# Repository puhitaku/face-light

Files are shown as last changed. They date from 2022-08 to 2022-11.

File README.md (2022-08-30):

# Face Light

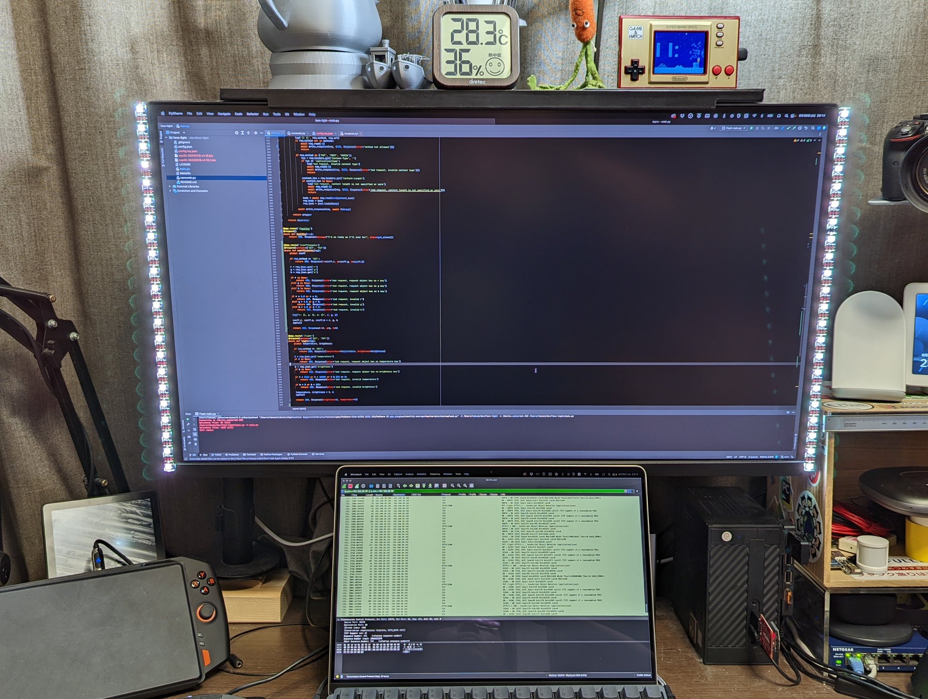
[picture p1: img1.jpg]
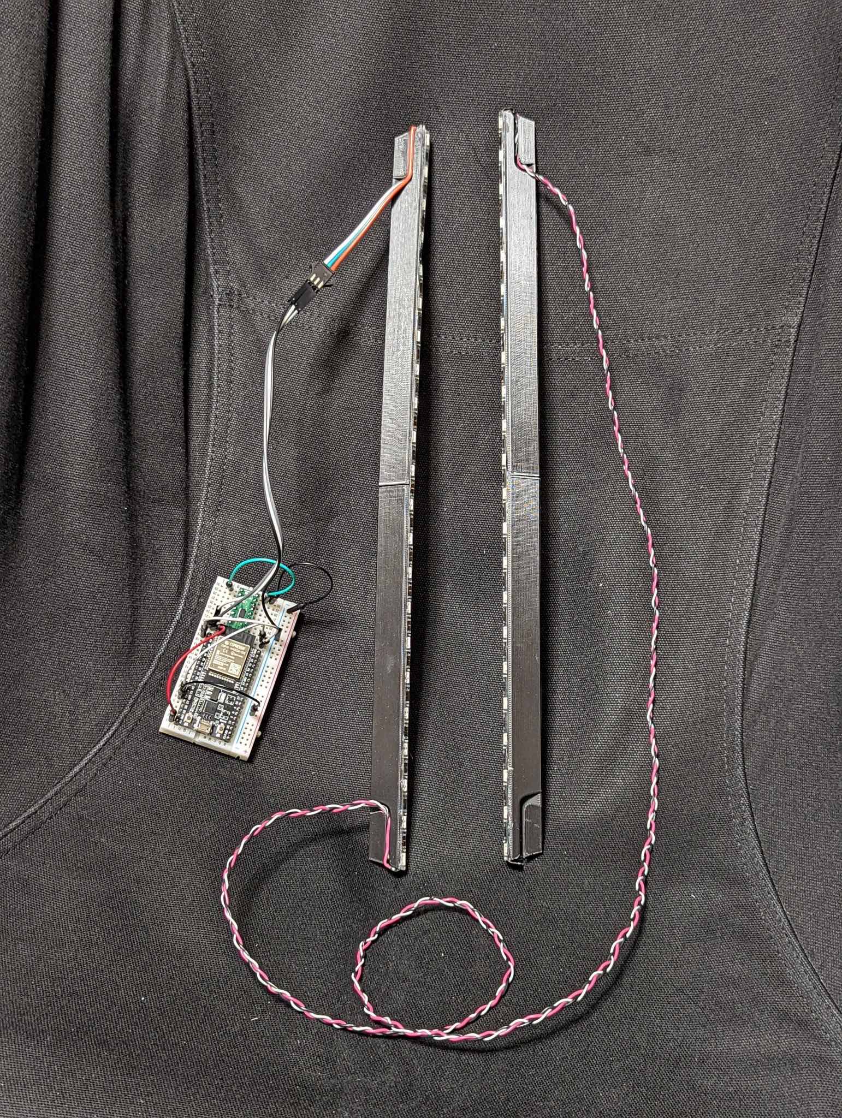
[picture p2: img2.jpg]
&nbsp;&nbsp;

3D-printed bars + NeoPixel LED strip + ESP32 + MicroPython = Face Light

### How to make yours

Prepare parts:

 - Open `face_light_bar.f3d`, adjust the length, and print it
   (A thin wooden bar basically does the same thing so you actually don't have to print it)
 - Any ESP32 module w/ USB-UART converter
 - Any NeoPixel(-compatible) LED strip
 - Level shifter between 3.3V -> 5V (for example: Fairchild Semiconductor FXMA108)

First, [install MicroPython on the ESP32 module](https://micropython.org/download/?port=esp32) (I tested it on MicroPython 1.15).

Fill the configuration file `config.json`.

 - `ssid`: your Wi-Fi AP's ESSID
 - `psk`: the pre-shared key (password)
 - `hostname`: ESP32's host name (advertised by mDNS)
 - `n_leds`: number of LEDs the strip has
 - `pin`: the pin number that the LED strip's DIN is connected to
 - `brightness`: default brightness on boot
 - `temperature`: default color temperature on boot
 - `coeff_r`: default coefficient of R channel on boot
 - `coeff_g`: default coefficient of G channel on boot
 - `coeff_b`: default coefficient of B channel on boot

After installing [ampy](https://github.com/scientifichackers/ampy), deploy the code and configuration.

```shell
ampy -p {serial_device} put main.py
ampy -p {serial_device} put nanoweb.py
ampy -p {serial_device} put config.json
```

Connect parts like:

 - ESP32 Vcc 3.3V -> Level shifter VA (Vdd of port A)
 - Vin (VBUS) 5V -> Level shifter VB (Vdd of port B)
 - Vin (VBUS) 5V -> LED strip Vin
 - ESP32 pin 12 -> Level shifter A0 (3.3V port bit 0)
 - Level shifter B0 (5V port bit 0) -> LED strip DIN
 - GND of everything

Send a request to turn the strip on. \
Note: If you're using Windows, you may not need the `.local` suffix in the URL.

```shell
curl -X PUT -H "Content-Type: application/json" -d '{"brightness": 255, "temperature": 6500}' http://face-light.local/light
```

Install the bar and the circuitry on your display! :tada:

### API reference

Call the REST API on port 80 to controll the LED strip.

#### /healthz

Returns a message.

Example response (pretty-printed):

```json
{
  "error": null,
  "message": "I'm as ready as I'll ever be!",
  "state": {
    "free": 56528
  }
}
```

 - `error` Optional[str]: error message
 - `message` str: passionate message from your ESP32
 - `state` -> `free` int: free memory in bytes

#### /coefficients (GET)

Get RGB coefficients.

Example response (pretty-printed):

```json
{
  "error": null,
  "r": 1.0,
  "g": 1.0,
  "b": 1.0
}
```

- `error` Optional[str]: error message
- `r` float: coefficient of R channel (0.0 <= r <= 1.0)
- `g` float: coefficient of G channel (0.0 <= g <= 1.0)
- `b` float: coefficient of B channel (0.0 <= b <= 1.0)

#### /coefficients (PUT)

Set RGB coefficients.

Example request (pretty-printed):

```json
{
  "r": 0.9,
  "g": 1.0,
  "b": 1.0
}
```

- `r` float: coefficient of R channel (0.0 <= r <= 1.0)
- `g` float: coefficient of G channel (0.0 <= g <= 1.0)
- `b` float: coefficient of B channel (0.0 <= b <= 1.0)

#### /light (GET)

Get the light's state.

Example response (pretty-printed):

```json
{
  "error": null,
  "brightness": 255,
  "temperature": 2400
}
```

- `error` Optional[str]: error message
- `brightness` int: brightness (0 <= b <= 255)
- `temperature` int: color temperature (2000 <= t <= 10000, must be a multiple of 100 like 2000, 2100, ...)

#### /light (PUT)

Set the light's state.

Example request (pretty-printed):

```json
{
  "brightness": 128,
  "temperature": 7000 
}
```

- `brightness` int: brightness (0 <= b <= 255)
- `temperature` int: color temperature (2000 <= t <= 10000, must be a multiple of 100 like 2000, 2100, ...)

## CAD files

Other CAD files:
face_light_bar.f3d

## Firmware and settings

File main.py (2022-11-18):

import gc
import json
import machine
import network
import neopixel
import time
import uasyncio

from collections import OrderedDict

from nanoweb import Nanoweb

loop = uasyncio.get_event_loop()
wifi = network.WLAN(network.STA_IF)
np = None
party = None

temperature = 6500
brightness = 0


class Coefficients:
    r = 1.0
    g = 1.0
    b = 1.0


coeff = Coefficients()

# Table from https://andi-siess.de/rgb-to-color-temperature/
kelvin2rgb_items = [
    (2000, (255, 138, 18)),
    (2100, (255, 142, 33)),
    (2200, (255, 147, 44)),
    (2300, (255, 152, 54)),
    (2400, (255, 157, 63)),
    (2500, (255, 161, 72)),
    (2600, (255, 165, 79)),
    (2700, (255, 169, 87)),
    (2800, (255, 173, 94)),
    (2900, (255, 177, 101)),
    (3000, (255, 180, 107)),
    (3100, (255, 184, 114)),
    (3200, (255, 187, 120)),
    (3300, (255, 190, 126)),
    (3400, (255, 193, 132)),
    (3500, (255, 196, 137)),
    (3600, (255, 199, 143)),
    (3700, (255, 201, 148)),
    (3800, (255, 204, 153)),
    (3900, (255, 206, 159)),
    (4000, (255, 209, 163)),
    (4100, (255, 211, 168)),
    (4200, (255, 213, 173)),
    (4300, (255, 215, 177)),
    (4400, (255, 217, 182)),
    (4500, (255, 219, 186)),
    (4600, (255, 221, 190)),
    (4700, (255, 223, 194)),
    (4800, (255, 225, 198)),
    (4900, (255, 227, 202)),
    (5000, (255, 228, 206)),
    (5100, (255, 230, 210)),
    (5200, (255, 232, 213)),
    (5300, (255, 233, 217)),
    (5400, (255, 235, 220)),
    (5500, (255, 236, 224)),
    (5600, (255, 238, 227)),
    (5700, (255, 239, 230)),
    (5800, (255, 240, 233)),
    (5900, (255, 242, 236)),
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
]

kelvin2rgb = OrderedDict(kelvin2rgb_items)
app = Nanoweb(port=80)


def log(fmt, *o):
    print('[{:08.3f}]'.format(time.ticks_ms() / 1000), fmt.format(*o))


def get_state():
    return {'free': gc.mem_free()}


def apply():
    global np, temperature, brightness, coeff

    t = kelvin2rgb[temperature]
    r = brightness / 255
    np.fill((int(t[0] * r * coeff.r), int(t[1] * r * coeff.g), int(t[2] * r * coeff.b)))
    np.write()


class Response:
    error = None

    def __init__(self, **kwargs):
        self.error = None
        for k, v in kwargs.items():
            setattr(self, k, v)

    def jsonify(self) -> str:
        d = dict()
        items = ((k, v) for k, v in self.__dict__.items() if not k.startswith('__'))
        for k, v in items:
            d[k] = v
        return json.dumps(d)


def respond(methods=('GET',)):
    """A mixin decorator to simplify handlers like Flask"""

    def decorator(fn):
        async def write_response(req, res):
            if isinstance(res, tuple):
                # Tuple = a tuple of status code and the body
                status, body = res
            else:
                # Others = implies "200 OK"
                status, body = 200, res

                # Start writing the response header
            await req.write('HTTP/1.1 {}\r\n'.format(status))

            if isinstance(body, dict) or isinstance(body, list):
                # Dict or list = jsonified
                await req.write('Content-Type: application/json\r\n\r\n')
                await req.write(json.dumps(body))
            elif isinstance(body, Response):
                await req.write('Content-Type: application/json\r\n\r\n')
                await req.write(body.jsonify())
            else:
                # Others = implies a plain text and be transmitted as-is
                await req.write('Content-Type: text/plain\r\n\r\n')
                await req.write(body)

        async def wrapper(req):
            log('{} {}', req.method, req.url)
            if req.method not in methods:
                await req.read(-1)
                await write_response(req, (405, Response(error='method not allowed')))
                return

            if req.method in ('PUT', 'POST', 'PATCH'):
                typ = req.headers.get('Content-Type', '')
                if typ != 'application/json':
                    log('bad request, invalid content type')
                    await req.read(-1)
                    await write_response(req, (400, Response(error='bad request, invalid content type')))
                    return

                content_len = req.headers.get('Content-Length')
                if content_len is None:
                    log('bad request, content length is not specified or zero')
                    await req.read(-1)
                    await write_response(req, (400, Response(error='bad request, content length is not specified or zero')))
                    return

                body = await req.read(int(content_len))
                req.body = body
                req.json = json.loads(body)

            await write_response(req, await fn(req))

        return wrapper

    return decorator


@app.route('/healthz')
@respond()
async def healthz(req):
    return 200, Response(message="I'm as ready as I'll ever be!", state=get_state())


@app.route('/coefficients')
@respond(methods=('GET', 'PUT'))
async def coefficients(req):
    global coeff

    if req.method == 'GET':
        return 200, Response(r=coeff.r, g=coeff.g, b=coeff.b)

    r = req.json.get('r')
    g = req.json.get('g')
    b = req.json.get('b')

    if r is None:
        return 400, Response(error='bad request, request object has no r key')
    elif g is None:
        return 400, Response(error='bad request, request object has no g key')
    elif b is None:
        return 400, Response(error='bad request, request object has no b key')

    if r > 1.0 or r < 0:
        return 400, Response(error='bad request, invalid r')
    elif g > 1.0 or g < 0:
        return 400, Response(error='bad request, invalid g')
    elif b > 1.0 or b < 0:
        return 400, Response(error='bad request, invalid b')

    log("r: {}, g: {}, b: {}", r, g, b)

    coeff.r, coeff.g, coeff.b = r, g, b
    apply()

    return 200, Response(r=r, g=g, b=b)


@app.route('/light')
@respond(methods=('GET', 'PUT'))
async def light(req):
    global temperature, brightness

    if req.method == 'GET':
        return 200, Response(temperature=temperature, brightness=brightness)

    t = req.json.get('temperature')
    if t is None:
        return 400, Response(error='bad request, request object has no temperature key')

    b = req.json.get('brightness')
    if b is None:
        return 400, Response(error='bad request, request object has no brightness key')

    if t < 2000 or t > 10000 or t % 100 != 0:
        return 400, Response(error='bad request, invalid temperature')

    if b < 0 or b > 255:
        return 400, Response(error='bad request, invalid brightness')

    temperature, brightness = t, b
    apply()

    return 200, Response(brightness=b, temperature=t)


@app.route('/party_mode')
@respond(methods=('GET', 'PUT'))
async def party_mode(req):
    global loop, np, party

    async def illuminate():
        try:
            while True:
                np.fill((255, 0, 0))
                np.write()
                await uasyncio.sleep(0.2)
                np.fill((0, 255, 0))
                np.write()
                await uasyncio.sleep(0.2)
                np.fill((0, 0, 255))
                np.write()
                await uasyncio.sleep(0.2)
        finally:
            # Restore the normal color
            apply()

    if req.method == 'GET':
        return 200, Response(enable=party is not None)

    enable = req.json.get('enable')
    if enable is None:
        return 400, Response(error='bad request, request object has no enable key')

    if enable:
        if party is None:
            party = loop.create_task(illuminate())
    else:
        if party is not None:
            party.cancel()
            party = None

    return 200, Response(enable=enable)


def wifi_up(ssid, psk, hostname):
    if wifi.isconnected():
        return True

    log('Connecting to an AP')
    log('SSID: {}, PSK: (hidden)', ssid)

    wifi.active(True)
    wifi.config(dhcp_hostname=hostname)
    wifi.connect(ssid, psk)

    for _ in range(10):
        if wifi.isconnected():
            break
        time.sleep(1)
    else:
        log('Failed to connect: timed out')
        return False

    log('Successfully connected')
    return True


def main():
    global np, loop, brightness, temperature, coeff

    with open('config.json', 'r') as f:
        conf = json.load(f)

    brightness = conf.get('brightness', 0)
    temperature = conf.get('temperature', 6500)
    coeff.r = conf.get('coeff_r', 1.0)
    coeff.g = conf.get('coeff_g', 1.0)
    coeff.b = conf.get('coeff_b', 1.0)

    np = neopixel.NeoPixel(machine.Pin(conf.get('pin', 12)), conf['n_leds'])
    apply()

    while True:
        ok = wifi_up(conf['ssid'], conf['psk'], conf['hostname'])
        if not ok:
            log('Failed to establish a Wi-Fi connection, resetting')
            machine.reset()

        log('Address: {}, Netmask: {}, GW: {}, DNS: {}', *wifi.ifconfig())
        gc.collect()

        loop.create_task(app.run())

        try:
            loop.run_forever()
        finally:
            log("Interrupting the server")


main()

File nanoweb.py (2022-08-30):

import uasyncio as asyncio
import uerrno


class HttpError(Exception):
    pass


class Request:
    url = ""
    method = ""
    headers = {}
    route = ""
    read = None
    write = None
    close = None


async def write(request, data):
    await request.write(
        data.encode('ISO-8859-1') if type(data) == str else data
    )


async def error(request, code, reason):
    await request.write("HTTP/1.1 %s %s\r\n\r\n" % (code, reason))
    await request.write("<h1>%s</h1>" % (reason))


async def send_file(request, filename, segment=64, binary=False):
    try:
        with open(filename, 'rb' if binary else 'r') as f:
            while True:
                data = f.read(segment)
                if not data:
                    break
                await request.write(data)
    except OSError as e:
        if e.args[0] != uerrno.ENOENT:
            raise
        raise HttpError(request, 404, "File Not Found")


class Nanoweb:

    extract_headers = ('Authorization', 'Content-Length', 'Content-Type')
    headers = {}

    routes = {}
    assets_extensions = ('html', 'css', 'js')

    callback_request = None
    callback_error = staticmethod(error)

    STATIC_DIR = 'nanoweb/'
    INDEX_FILE = STATIC_DIR + 'index.html'

    def __init__(self, port=80, address='0.0.0.0'):
        self.port = port
        self.address = address

    def route(self, route):
        """Route decorator"""
        def decorator(func):
            self.routes[route] = func
            return func
        return decorator

    async def generate_output(self, request, handler):
        """Generate output from handler

        `handler` can be :
         * dict representing the template context
         * string, considered as a path to a file
         * tuple where the first item is filename and the second
           is the template context
         * callable, the output of which is sent to the client
        """
        while True:
            if isinstance(handler, dict):
                handler = (request.url, handler)

            if isinstance(handler, str):
                await write(request, "HTTP/1.1 200 OK\r\n\r\n")
                await send_file(request, handler)
            elif isinstance(handler, tuple):
                await write(request, "HTTP/1.1 200 OK\r\n\r\n")
                filename, context = handler
                context = context() if callable(context) else context
                try:
                    with open(filename, "r") as f:
                        for l in f:
                            await write(request, l.format(**context))
                except OSError as e:
                    if e.args[0] != uerrno.ENOENT:
                        raise
                    raise HttpError(request, 404, "File Not Found")
            else:
                handler = await handler(request)
                if handler:
                    # handler can returns data that can be fed back
                    # to the input of the function
                    continue
            break

    async def handle(self, reader, writer):
        items = await reader.readline()
        items = items.decode('ascii').split()
        if len(items) != 3:
            return

        request = Request()
        request.read = reader.read
        request.write = writer.awrite
        request.close = writer.aclose

        request.method, request.url, version = items

        try:
            try:
                if version not in ("HTTP/1.0", "HTTP/1.1"):
                    raise HttpError(request, 505, "Version Not Supported")

                while True:
                    items = await reader.readline()
                    items = items.decode('ascii').split(":", 1)

                    if len(items) == 2:
                        header, value = items
                        value = value.strip()

                        if header in self.extract_headers:
                            request.headers[header] = value
                    elif len(items) == 1:
                        break

                if self.callback_request:
                    self.callback_request(request)

                if request.url in self.routes:
                    # 1. If current url exists in routes
                    request.route = request.url
                    await self.generate_output(request,
                                               self.routes[request.url])
                else:
                    # 2. Search url in routes with wildcard
                    for route, handler in self.routes.items():
                        if route == request.url \
                            or (route[-1] == '*' and
                                request.url.startswith(route[:-1])):
                            request.route = route
                            await self.generate_output(request, handler)
                            break
                    else:
                        # 3. Try to load index file
                        if request.url in ('', '/'):
                            await send_file(request, self.INDEX_FILE)
                        else:
                            # 4. Current url have an assets extension ?
                            for extension in self.assets_extensions:
                                if request.url.endswith('.' + extension):
                                    await send_file(
                                        request,
                                        '%s/%s' % (
                                            self.STATIC_DIR,
                                            request.url,
                                        ),
                                        binary=True,
                                    )
                                    break
                            else:
                                raise HttpError(request, 404, "File Not Found")
            except HttpError as e:
                request, code, message = e.args
                await self.callback_error(request, code, message)
        except OSError as e:
            # Skip ECONNRESET error (client abort request)
            if e.args[0] != uerrno.ECONNRESET:
                raise
        finally:
            await writer.aclose()

    async def run(self):
        return await asyncio.start_server(self.handle, self.address, self.port)

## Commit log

2022-08-29 Add main.py: loop over all available temperatures
2022-08-30 Load n_leds and pin number from the config
